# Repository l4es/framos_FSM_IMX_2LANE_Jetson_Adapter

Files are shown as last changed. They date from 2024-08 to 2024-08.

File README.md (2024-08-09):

# framos_FSM_IMX_2LANE_Jetson_Adapter

Adapter for Framos FSM (Sony IMX based) camera modules to Raspberry Pi 15-pin camera interface, available in official Nvidia Jetson Developer Kits  

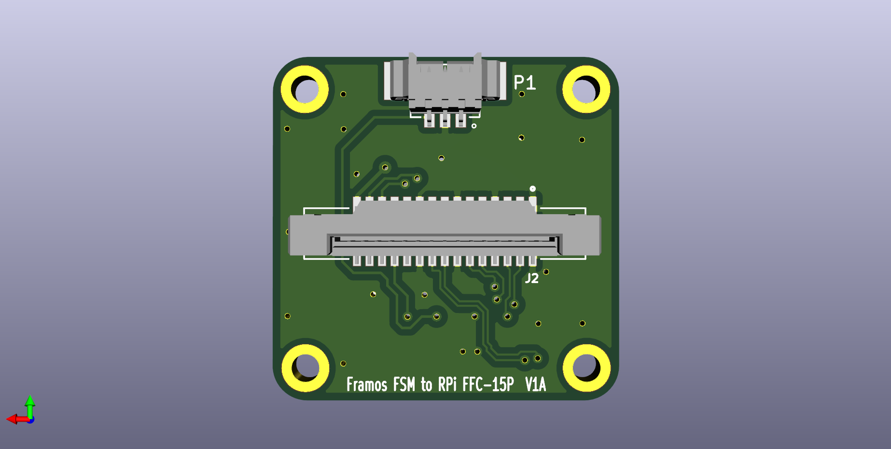
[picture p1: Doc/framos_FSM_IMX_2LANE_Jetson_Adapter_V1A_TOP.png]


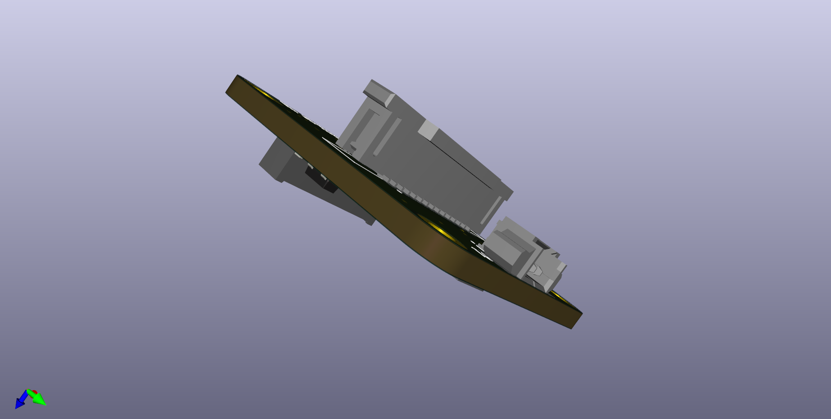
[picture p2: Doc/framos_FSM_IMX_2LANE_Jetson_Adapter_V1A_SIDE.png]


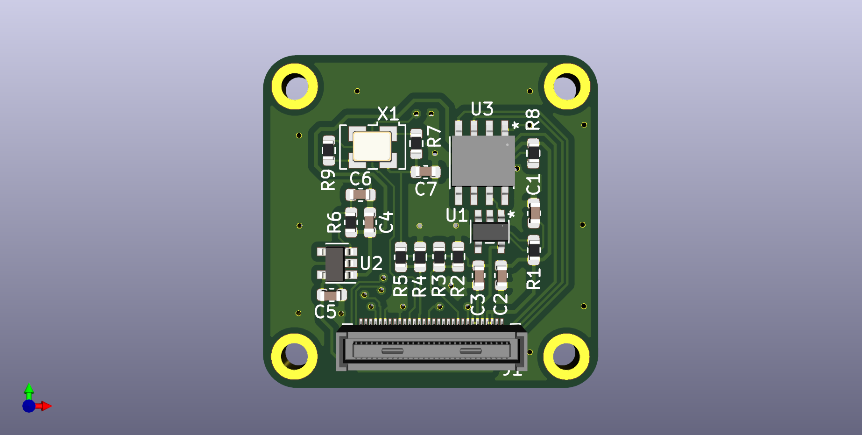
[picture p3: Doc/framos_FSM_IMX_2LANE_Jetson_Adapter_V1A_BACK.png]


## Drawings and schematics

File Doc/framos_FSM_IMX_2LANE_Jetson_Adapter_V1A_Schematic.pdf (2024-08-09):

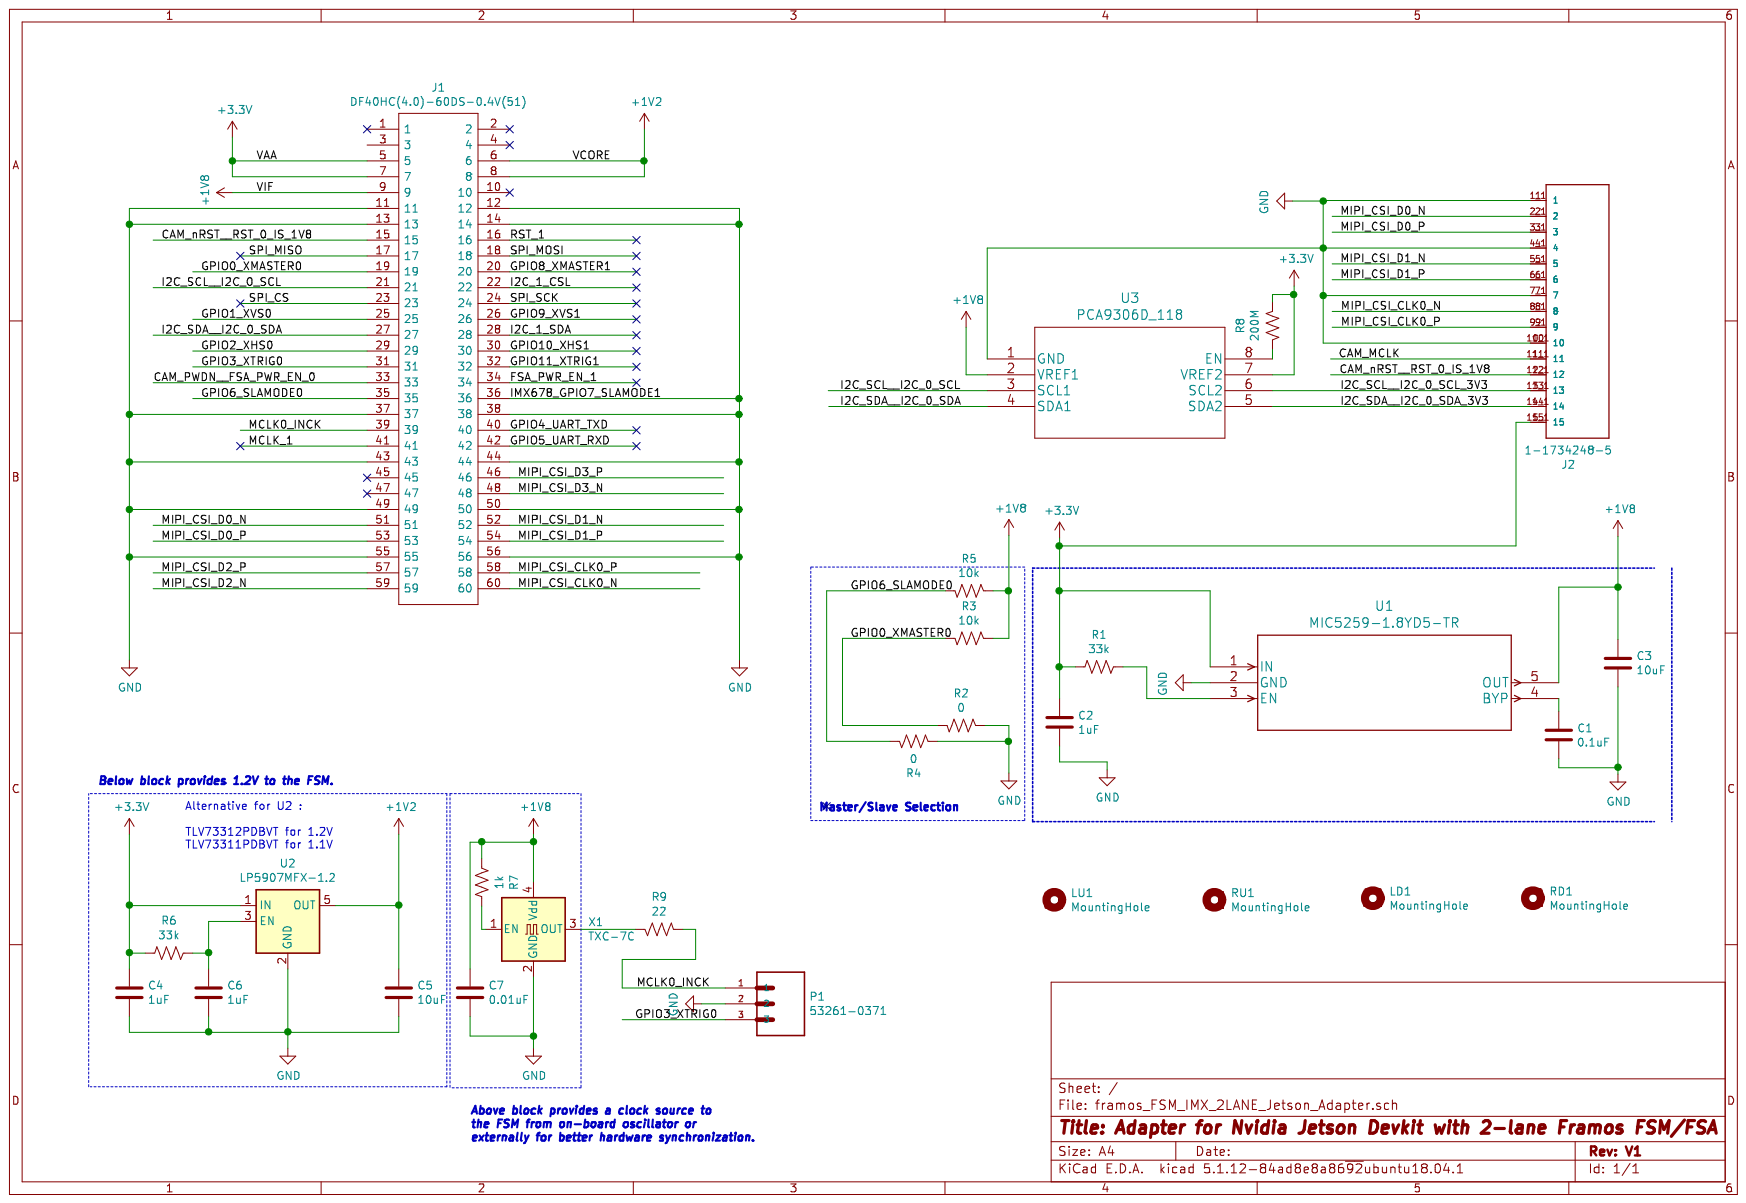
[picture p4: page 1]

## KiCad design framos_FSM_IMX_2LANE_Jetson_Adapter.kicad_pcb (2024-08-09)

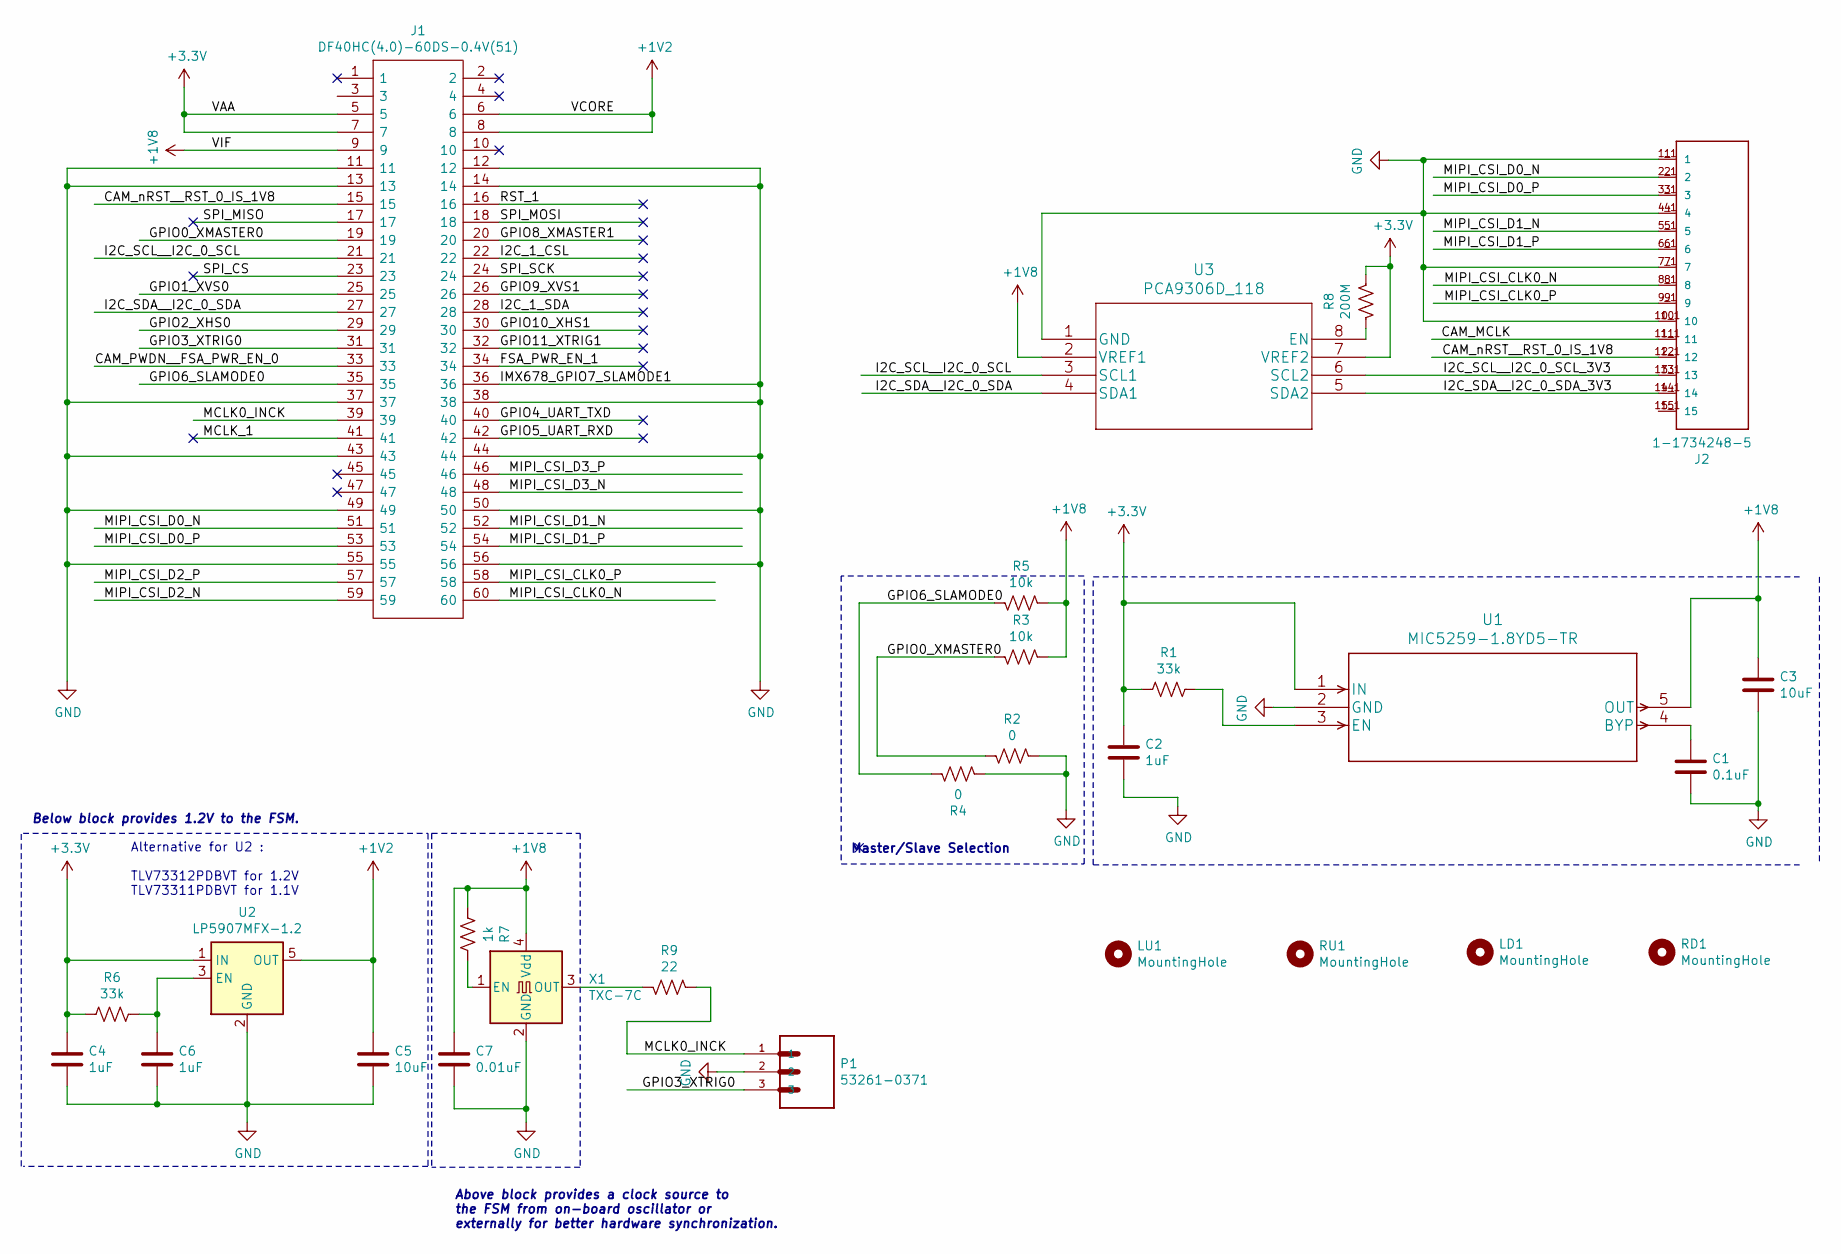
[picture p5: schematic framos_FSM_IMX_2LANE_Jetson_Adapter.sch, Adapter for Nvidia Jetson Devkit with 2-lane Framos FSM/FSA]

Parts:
C1: 0.1uF; C_0603_1608Metric
C2, C4, C6: 1uF; C_0603_1608Metric
C3, C5: 10uF; C_0603_1608Metric
C7: 0.01uF; C_0603_1608Metric
J1: DF40HC(4.0)-60DS-0.4V(51); DF40HC4060DS04V51; Manufacturer_Part_Number DF40HC(4.0)-60DS-0.4V(51); Mouser Part Number 798-DF4HC4060DS04V51
J2: 1-1734248-5; TE_1-1734248-5
LD1: MountingHole; MountingHole_2.2mm_M2_ISO14580_Pad
LU1: MountingHole; MountingHole_2.2mm_M2_ISO14580_Pad
P1: 53261-0371; MOLEX_53261-0371
R1, R6: 33k; R_0603_1608Metric
R2, R4: 0; R_0603_1608Metric
R3, R5: 10k; R_0603_1608Metric
R7: 1k; R_0603_1608Metric
R8: 200M; R_0603_1608Metric
R9: 22; R_0603_1608Metric
RD1: MountingHole; MountingHole_2.2mm_M2_ISO14580_Pad
RU1: MountingHole; MountingHole_2.2mm_M2_ISO14580_Pad
U1: MIC5259-1.8YD5-TR; MIC5259-2.8YD5-TR
U2: LP5907MFX-1.2; SOT-23-5
U3: PCA9306D_118; PCA9306D
X1: TXC-7C; Oscillator_SMD_TXC_7C-4Pin_5.0x3.2mm

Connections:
+1V2: C5.1, J1.6, J1.8, U2.5 (OUT)
+1V8: C3.1, C7.1, J1.9, R3.2, R5.2, R7.2, U1.5 (OUT), U3.2 (VREF1), X1.4 (Vdd)
/CAM_MCLK: J2.11, J2.11_1 (11)
/CAM_PWDN__FSA_PWR_EN_0: J1.33
/CAM_nRST__RST_0_IS_1V8: J1.15, J2.12, J2.12_1 (12)
/FSA_PWR_EN_1: J1.34
/GPIO0_XMASTER0: J1.19, R2.1, R3.1
/GPIO1_XVS0: J1.25
/GPIO2_XHS0: J1.29
/GPIO3_XTRIG0: J1.31, P1.3
/GPIO4_UART_TXD: J1.40
/GPIO5_UART_RXD: J1.42
/GPIO6_SLAMODE0: J1.35, R4.2, R5.1
/GPIO8_XMASTER1: J1.20
/GPIO9_XVS1: J1.26
/GPIO10_XHS1: J1.30
/GPIO11_XTRIG1: J1.32
/I2C_1_CSL: J1.22
/I2C_1_SDA: J1.28
/I2C_SCL__I2C_0_SCL: J1.21, U3.3 (SCL1)
/I2C_SCL__I2C_0_SCL_3V3: J2.13, J2.13_1 (13), U3.6 (SCL2)
/I2C_SDA__I2C_0_SDA: J1.27, U3.4 (SDA1)
/I2C_SDA__I2C_0_SDA_3V3: J2.14, J2.14_1 (14), U3.5 (SDA2)
/MCLK0_INCK: J1.39, P1.1, R9.2
/MCLK_1: J1.41
/MIPI_CSI_CLK0_N: J1.60, J2.8, J2.8_1 (8)
/MIPI_CSI_CLK0_P: J1.58, J2.9, J2.9_1 (9)
/MIPI_CSI_D0_N: J1.51, J2.2, J2.2_1 (2)
/MIPI_CSI_D0_P: J1.53, J2.3, J2.3_1 (3)
/MIPI_CSI_D1_N: J1.52, J2.5, J2.5_1 (5)
/MIPI_CSI_D1_P: J1.54, J2.6, J2.6_1 (6)
/MIPI_CSI_D2_N: J1.59
/MIPI_CSI_D2_P: J1.57
/MIPI_CSI_D3_N: J1.48
/MIPI_CSI_D3_P: J1.46
/RST_1: J1.16
/SPI_CS: J1.23
/SPI_MISO: J1.17
/SPI_MOSI: J1.18
/SPI_SCK: J1.24
GND: C1.2, C2.2, C3.2, C4.2, C5.2, C6.2, C7.2, J1.11, J1.12, J1.13, J1.14, J1.36, J1.37, J1.38, J1.43, J1.44, J1.49, J1.50, J1.55, J1.56, J2.1, J2.1_1 (1), J2.4, J2.4_1 (4), J2.7, J2.7_1 (7), J2.10, J2.10_1 (10), P1.2, R2.2, R4.1, U1.2 (GND), U2.2 (GND), U3.1 (GND), X1.2 (GND)
unnamed: C1.1, U1.4 (BYP)
unnamed: C6.1, R6.1, U2.3 (EN)
unnamed: R1.1, U1.3 (EN)
unnamed: R7.1, X1.1 (EN)
unnamed: R8.1, U3.8 (EN)
unnamed: R9.1, X1.3 (OUT)

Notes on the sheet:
Alternative for U2 : TLV73312PDBVT for 1.2V TLV73311PDBVT for 1.1V
Below block provides 1.2V to the FSM.
Above block provides a clock source to the FSM from on-board oscillator or externally for better hardware synchronization.
Master/Slave Selection

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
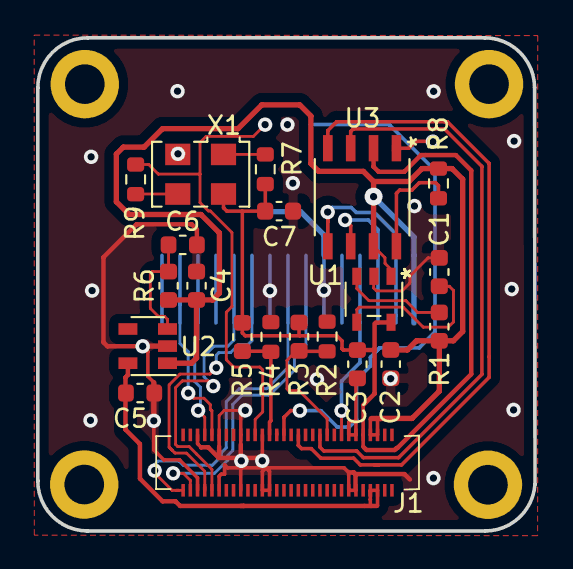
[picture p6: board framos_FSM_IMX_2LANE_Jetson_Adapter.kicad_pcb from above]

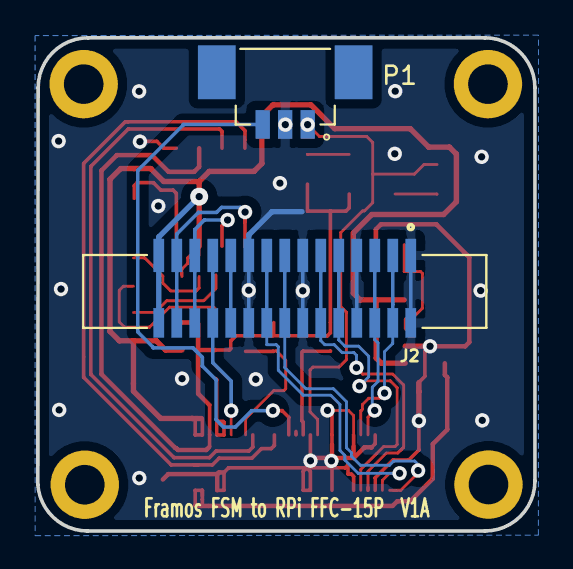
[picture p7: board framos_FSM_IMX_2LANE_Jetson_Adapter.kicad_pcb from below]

Board: 2 copper layers, 27.6 x 27.4 mm, 27 parts (2 on the bottom side), 26 nets.

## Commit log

2024-08-09 Add V1A version
    [framos_FSM_IMX_2LANE_Jetson_Adapter-B_Cu.gbr, framos_FSM_IMX_2LANE_Jetson_Adapter-B_Mask.gbr, framos_FSM_IMX_2LANE_Jetson_Adapter-B_Paste.gbr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]
2024-08-09 Add 3V3 power supply from J2
2024-08-09 Add documentation
    [framos_FSM_IMX_2LANE_Jetson_Adapter.sch]
2024-08-09 Update documentation to show board's images

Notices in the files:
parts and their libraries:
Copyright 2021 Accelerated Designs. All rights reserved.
